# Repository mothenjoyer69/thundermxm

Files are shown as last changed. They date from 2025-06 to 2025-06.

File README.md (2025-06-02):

# thundermxm
An open source MXM eGPU board featuring an Intel JHL7440 TB3 controller module, with support for 200W of power. It supports standard MXM3.0A/B cards, as well as Clevo style cards, and supports both TB3 display tunneling and native display output. 

* Very WIP Kicad render
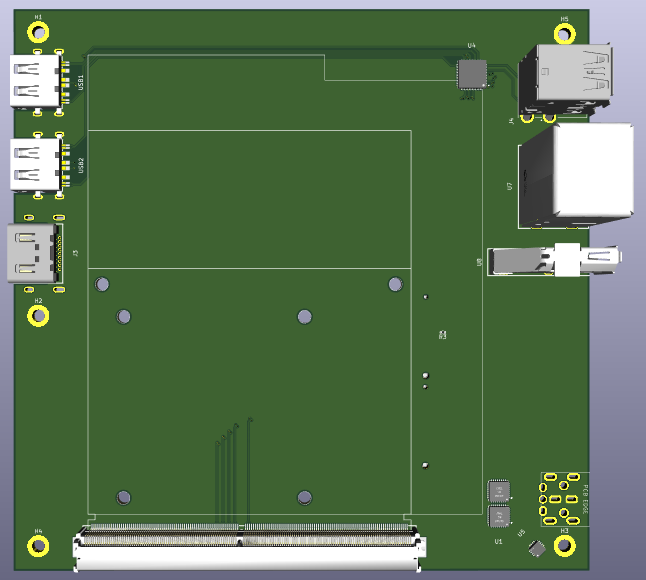
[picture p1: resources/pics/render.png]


# Specs:
* Intel JHL7440 TB3 module 
* MXM3.0b interface, with full support for Clevo power connectors
* PCIe 3.0 x4 link
* All available I/O broken out:
    * 3x DP + 1x HDMI for monitor and VR headset support
    * USB3.0 downstream ports for various devices
* Dell-style 15A barrel jack connector
* Fan header with PWM control (Planned)

## To-do:
* Finalize schematics, now that reference files for the TB3 module have arrived
* Finish routing (waiting on schematic)

This project wouldn't exist without the help of [wifi](https://github.com/a-little-wifi/) and her incredible [MXM Immobilizer project](https://github.com/a-little-wifi/mxm-immobilizer). I also stole the cool MXM outline from there :3

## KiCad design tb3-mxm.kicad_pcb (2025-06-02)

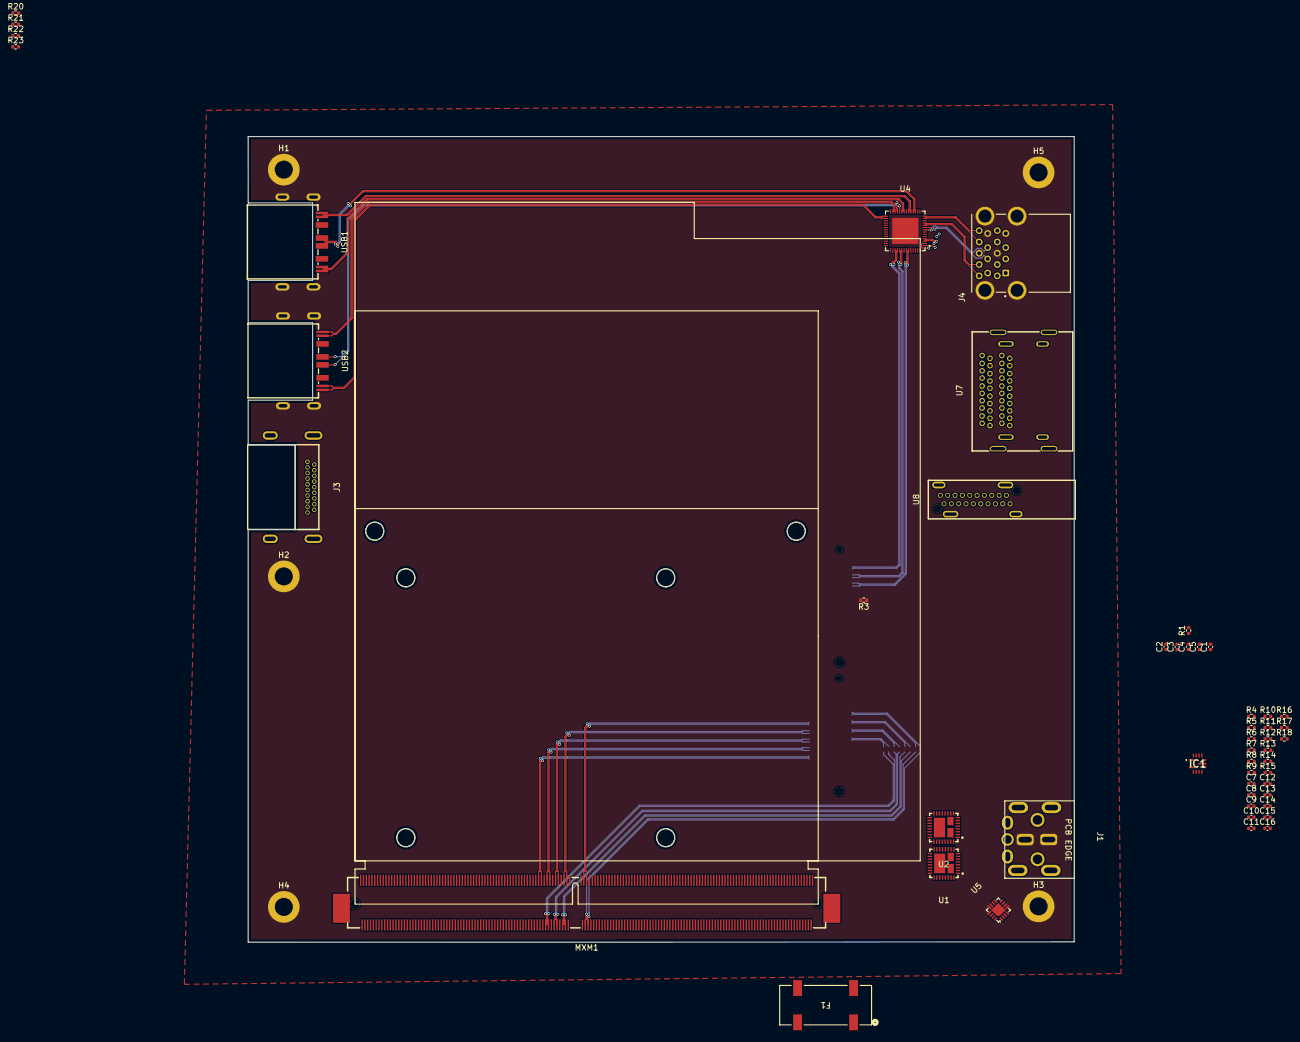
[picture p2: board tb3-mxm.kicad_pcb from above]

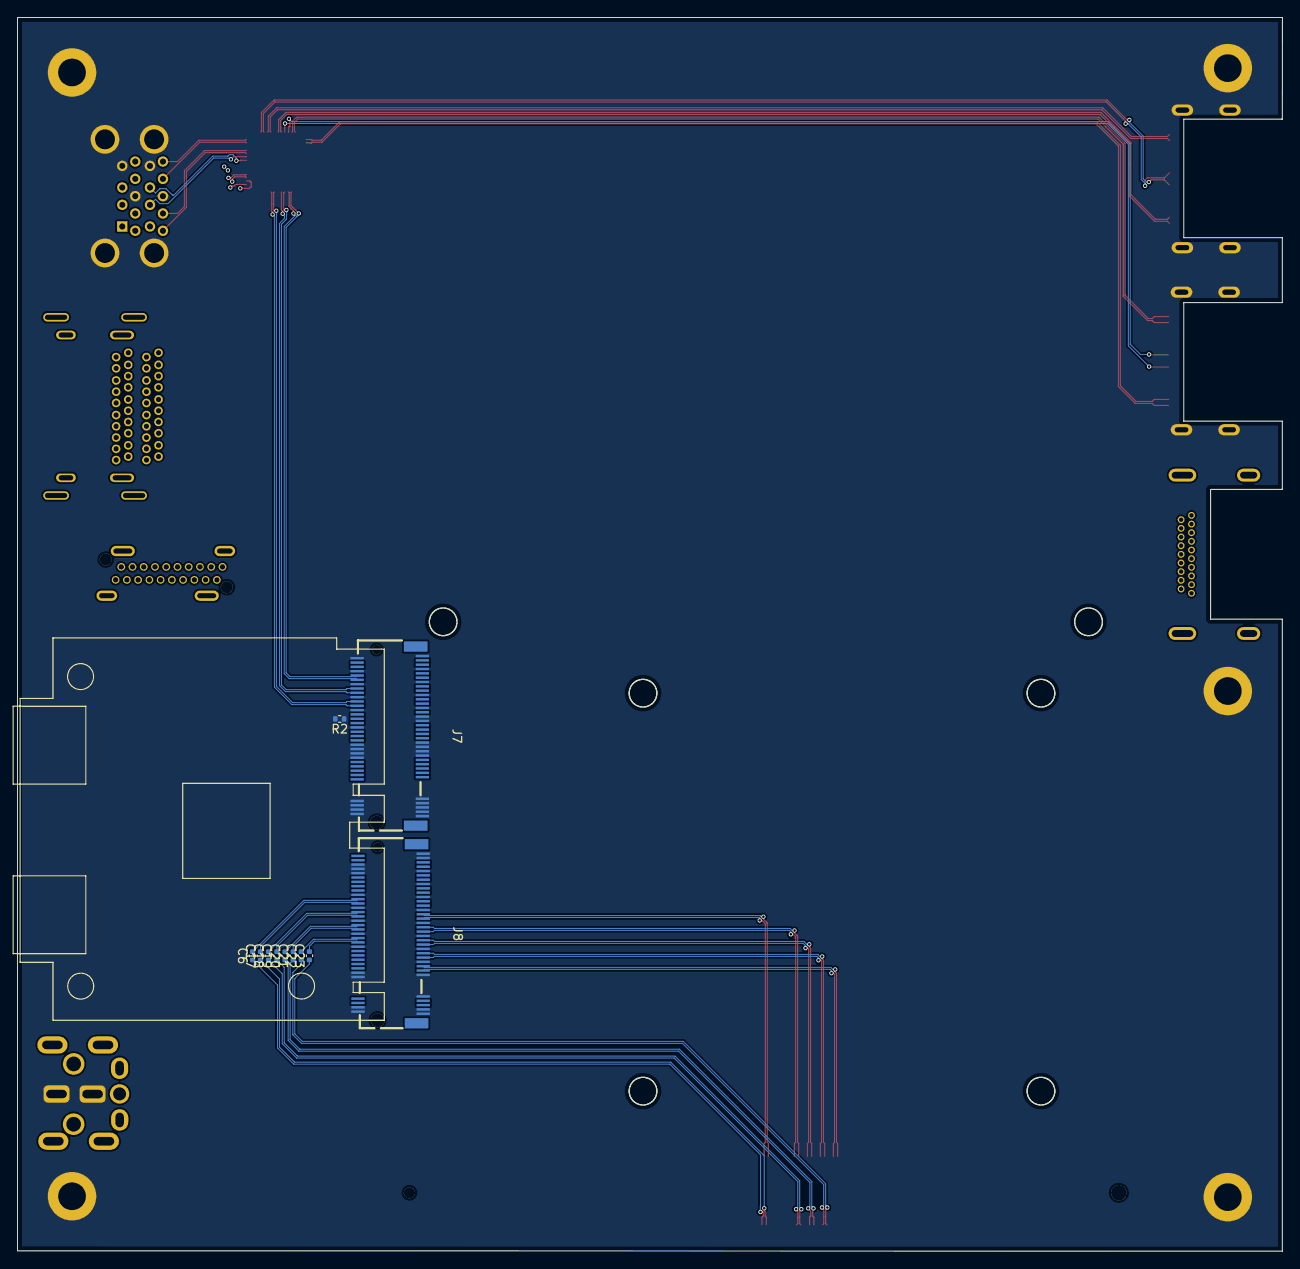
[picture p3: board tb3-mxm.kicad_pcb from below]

Board: 4 copper layers, 146.2 x 142.6 mm, 66 parts (11 on the bottom side), 86 nets.

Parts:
C1, C3: 10uF/16v; C_0402_1005Metric
C2, C4, C5: 1uF/16v; C_0402_1005Metric
C6, C17, C18, C19, C20, C21, C22, C23: 100n; C_0402_1005Metric
C7: 22uF/25V; C_0402_1005Metric
C8: 22uF/25v; C_0402_1005Metric
C9: 10n/25v; C_0402_1005Metric
C10: 2.2uF/25v; C_0402_1005Metric
C11: 1u/50v; C_0402_1005Metric
C12, C15: 22uF/35v; C_0402_1005Metric
C13, C14: 220uF/16V; C_0402_1005Metric
C16: 18p/25v; C_0402_1005Metric
F1: Fuse; 3588_KEY
H1, H2, H3, H4, H5: MountingHole_Pad; MountingHole_3.2mm_M3_DIN965_Pad
IC1: MP2491CGQB-P; MP2491CGQBP
J1: Jack-DC; DC-505
J3: HDMI_FRONT; HDMI-SMD_U-C-19DD-W-1
J4: USB3_DOUBLE; MOLEX_0484060003
J7: M.2_1_USB; PCI-SMD_APCI0079-P002A
J8: M.2_2_PCIE; PCI-SMD_APCI0079-P002A
MXM1: AS0B826-S78B-7H; CONN-SMD_AS0B826-S78B-7H
R1, R3: 0k; R_0402_1005Metric
R2: 0k (NC); R_0402_1005Metric
R4, R10, R11, R14: 100k; R_0402_1005Metric
R5: 200k; R_0402_1005Metric
R6, R7, R8: 10k; R_0402_1005Metric
R9, R12, R13, R16, R17, R18: 0; R_0402_1005Metric
R15: 11k; R_0402_1005Metric
R20, R22, R23: R_Small; R_0402_1005Metric
R21: 80k; R_0402_1005Metric
U1: 5V-DCDC; MLP55-32_L5.0-W5.0-P0.50-TL-EP
U2: 3v3-DCDC; MLP55-32_L5.0-W5.0-P0.50-TL-EP
U4: USB5744T/2GX01; VQFN-56_L7.0-W7.0-P0.40-BR-EP4.6
U5: TPS55340RTER; VQFN-16_L3.0-W3.0-P0.50-BL-EP1.7
U7: DISPLAYPORT_DOUBLE; DP-TH_3VD11203-DPA1-4H
U8: DP_REAR; USB-TH_3VD21203-H7U0-4H
USB1: USB2_FRONT1; USB-A-SMD_HC-USB3.0-C345-P
USB2: USB2_FRONT2; USB-A-SMD_HC-USB3.0-C345-P

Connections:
+1V2: U4.5 (VDD12), U4.12 (VDD12), U4.15 (VDD12), U4.21 (VDD12), U4.28 (VDD12), U4.33 (VDD12), U4.43 (VDD12), U4.49 (VDD12)
+3V3: U4.16 (VDD33), U4.31 (VDD33), U4.37 (VBUS_DET), U4.44 (VDD33), U4.55 (VDD33)
+5V: J4.1 (VBUS_U1), J4.10 (VBUS_U2), USB1.1 (VBUS), USB1.4 (GND), USB2.1 (VBUS), USB2.4 (GND)
/MXM/PCIE_TX0_C_N: C22.1, MXM1.148 (PEX_TX0#)
/MXM/PCIE_TX0_C_P: C23.1, MXM1.150 (PEX_TX0)
/MXM/PCIE_TX1_C_N: C20.1, MXM1.142 (PEX_TX1#)
/MXM/PCIE_TX1_C_P: C21.1, MXM1.144 (PEX_TX1)
/MXM/PCIE_TX2_C_N: C18.1, MXM1.136 (PEX_TX2#)
/MXM/PCIE_TX2_C_P: C19.1, MXM1.138 (PEX_TX2)
/MXM/PCIE_TX3_C_N: C6.1, MXM1.120 (PEX_TX3#)
/MXM/PCIE_TX3_C_P: C17.1, MXM1.122 (PEX_TX3)
/POWER/AN_VCCHV_BST: IC1.9 (BST), R13.1
/POWER/AN_VCCHV_BST_R: C11.2, R13.2
/POWER/AN_VCCHV_FB: C16.2, IC1.6 (FB), R14.1, R15.2
/POWER/AN_VCCHV_ILIM: IC1.12 (ILIM), R10.2, R11.2
/POWER/DG_PDO_VSEL1_1: IC1.4 (VSEL1), R7.2, R17.1
/POWER/DG_PDO_VSEL2_2: IC1.5 (VSEL2), R8.2, R18.1
/POWER/DG_VCCHV_EN: C9.2, IC1.11 (EN), R4.2, R5.2, R16.1
/POWER/DG_VCCHV_MODE: IC1.10 (MODE), R9.2, R12.2
/POWER/DG_VCCHV_PG: IC1.13 (PG), R6.2
/POWER/PW_VCCHW_SW: C11.1, IC1.8 (SW)
/POWER/PW_VCHH_VCC: C10.1, IC1.3 (VCC), R6.1, R7.1, R8.1, R9.1
GND: C1.2, C2.2, C3.2, C4.2, C5.2, C7.1, C8.1, C9.1, C10.2, C12.2, C13.2, C14.2, C15.2, H1.1, H2.1, H3.1, H4.1, H5.1, IC1.2 (PGND), IC1.7 (AGND), J1.1 (GND), J4.4 (GND_U1), J4.7 (GND_DRAIN_U1), J4.13 (GND_U2), J4.16 (GND_DRAIN_U2), J4.S1 (SHIELD), J4.S2 (SHIELD__1), J4.S3 (SHIELD__2), J4.S4 (SHIELD__3), J7.1, J7.2, J7.7, J7.8, J7.13, J7.14, J7.19, J7.20, J7.25, J7.26, J7.29, J7.31, J7.34, J7.41, J7.42, J7.43, J7.44, J7.45, J7.46, J7.47, J7.48, J7.67, J7.68, J7.69, J7.70, J7.71, J7.72, J7.73, J7.74, J7.75, J8.1, J8.3, J8.6, J8.8, J8.9, J8.10, J8.15, J8.20, J8.21, J8.26, J8.27, J8.32, J8.33, J8.38, J8.39, J8.44, J8.45, J8.51, J8.56, J8.57, J8.58, J8.67, J8.72, J8.73, J8.74, J8.75, R4.1, R10.1, R11.1, R12.1, R15.1, R21.2, R22.2, U4.52 (ATEST), U4.57 (VSS), U5.5 (SYNC), U5.6 (AGND), U5.11 (PGND), U5.12 (PGND), U5.13 (PGND), U5.17 (EP), USB1.10 (GND), USB1.11 (GND), USB1.12 (GND), USB1.13 (GND), USB2.10 (GND), USB2.11 (GND), USB2.12 (GND), USB2.13 (GND)
MXM_VCC_20V: F1.3, MXM1.E1 (E1_PWR_SRC), MXM1.E2 (E2_PWR_SRC)
unnamed: U5.1 (SW), U5.15 (SW), U5.16 (SW)
unnamed: J7.28, R1.1
unnamed: J7.30, R2.1
unnamed: J7.32, R3.1
unnamed: MXM1.1 (5V), MXM1.3 (5V), MXM1.5 (5V), MXM1.7 (5V), MXM1.9 (5V)
unnamed: R20.1, U5.7 (COMP)
unnamed: R22.1, R23.2, U5.8 (FB)
unnamed: R21.1, U5.9 (FREQ)
PCIE_CLK100M_N: J8.53, MXM1.155 (PEX_REFCLK)
PCIE_CLK100M_P: J8.55, MXM1.153 (PEX_REFCLK#)
PCIE_RX0_N: J8.47, MXM1.149 (PEX_RX0)
PCIE_RX0_P: J8.49, MXM1.147 (PEX_RX0#)
PCIE_RX1_N: J8.41, MXM1.143 (PEX_RX1)
PCIE_RX1_P: J8.43, MXM1.141 (PEX_RX1#)
PCIE_RX2_N: J8.35, MXM1.137 (PEX_RX2)
PCIE_RX2_P: J8.37, MXM1.135 (PEX_RX2#)
PCIE_RX3_N: J8.29, MXM1.123 (PEX_RX3)
PCIE_RX3_P: J8.31, MXM1.121 (PEX_RX3#)
PCIE_TX0_N: C22.2, J8.40
PCIE_TX0_P: C23.2, J8.42
PCIE_TX1_N: C20.2, J8.34
PCIE_TX1_P: C21.2, J8.36
PCIE_TX2_N: C18.2, J8.28
PCIE_TX2_P: C19.2, J8.30
PCIE_TX3_N: C6.2, J8.22
PCIE_TX3_P: C17.2, J8.24
PW_VCC3v3: C3.1, C4.1, C5.1, J8.68, J8.69, J8.70, J8.71
PW_VCC5v0_SYS: C1.1, C2.1, J8.2, J8.4
PW_VCC_TBTA_VBUS: C12.1, C13.1, C14.1, C15.1, C16.1, J7.49, J7.50, J7.51, J7.52, J7.53, J7.54, J7.55, J7.56, J7.57, J7.58, R14.2
PW_VCC_TBTB_VBUS: J7.33, J7.35, J7.36, J7.37, J7.38, J7.39, J7.40
USB0_D_N: J7.12, U4.46 (USB2UP_DM)
USB0_D_P: J7.10, U4.45 (USB2UP_DP)
USB0_SSRX1_N: J7.24, U4.51 (USB3UP_RXDM)
USB0_SSRX1_P: J7.22, U4.50 (USB3UP_RXDP)
USB0_SSTX1_N: J7.18, U4.48 (USB3UP_TXDM)
USB0_SSTX1_P: J7.16, U4.47 (USB3UP_TXDP)
USB1_D_N: J4.2 (D-_U1), U4.2 (USB2DN_DM1/~PRT_DIS_M1)
USB1_D_P: J4.3 (D+_U1), U4.1 (USB2DN_DP1/~PRT_DIS_P1)
USB1_SSRX_N: J4.5 (STDA_SSRX-_U1), U4.6 (USB3DN_RXDP1)
USB1_SSRX_P: J4.6 (STDA_SSRX+_U1), U4.7 (USB3DN_RXDM1)
USB1_SSTX_N: J4.8 (STDA_SSTX-_U1), U4.4 (USB3DN_TXDM1)
USB1_SSTX_P: J4.9 (STDA_SSTX+_U1), U4.3 (USB3DN_TXDP1)
USB2_D_N: J4.11 (D-_U2), U4.9 (USB2DN_DM2/~PRT_DIS_M2)
USB2_D_P: J4.12 (D+_U2), U4.8 (USB2DN_DP2/~PRT_DIS_P2)
USB2_SSRX_N: J4.14 (STDA_SSRX-_U2), U4.14 (USB3DN_RXDM2)
USB2_SSRX_P: J4.15 (STDA_SSRX+_U2), U4.13 (USB3DN_RXDP2)
USB2_SSTX_N: J4.17 (STDA_SSTX-_U2), U4.11 (USB3DN_TXDM2)
USB2_SSTX_P: J4.18 (STDA_SSTX+_U2), U4.10 (USB3DN_TXDP2)
USB3_D_N: U4.18 (USB2DN_DM3/~PRT_DIS_M3), USB1.2 (D-)
USB3_D_P: U4.17 (USB2DN_DP3/~PRT_DIS_P3), USB1.3 (D+)
USB3_SSRX_N: U4.23 (USB3DN_RXDM3), USB1.5 (STDA_SSRX-)
USB3_SSRX_P: U4.22 (USB3DN_RXDP3), USB1.6 (STDA_SSRX+)
USB3_SSTX_N: U4.20 (USB3DN_TXDM3), USB1.8 (STDA_SSTX-)
USB3_SSTX_P: U4.19 (USB3DN_TXDP3), USB1.9 (STDA_SSTX+)
USB4_D_N: U4.25 (USB2DN_DM4/~PRT_DIS_M4), USB2.2 (D-)
USB4_D_P: U4.24 (USB2DN_DP4/~PRT_DIS_P4), USB2.3 (D+)
USB4_SSRX_N: U4.30 (USB3DN_RXDM4), USB2.5 (STDA_SSRX-)
USB4_SSRX_P: U4.29 (USB3DN_RXDP4), USB2.6 (STDA_SSRX+)
USB4_SSTX_N: U4.27 (USB3DN_TXDM4), USB2.8 (STDA_SSTX-)
USB4_SSTX_P: U4.26 (USB3DN_TXDP4), USB2.9 (STDA_SSTX+)
VCC_22V: C7.2, C8.2, IC1.1 (IN), R5.1, R23.1
VIN_20V: F1.1, J1.2 (V+), U5.2 (VIN), U5.3 (EN)
